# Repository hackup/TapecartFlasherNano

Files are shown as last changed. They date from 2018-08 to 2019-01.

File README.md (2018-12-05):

# TapecartFlasher Nano

This is a shield for Arduino Nano and compatible boards to be used with the software from the [TapecartFlasher project](https://github.com/detlefgerhardt/TapecartFlasher). It allows fast and easy transfer of data from a PC or a connected micro SD card to a [Tapecart](https://github.com/ikorb/tapecart) device. More details are available on [hackup.net](https://www.hackup.net/tag/tapecartflasher/).

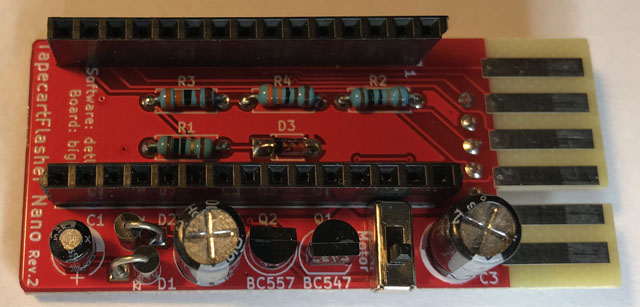
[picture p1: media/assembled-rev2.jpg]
TapecartFlasher Nano, Rev.2

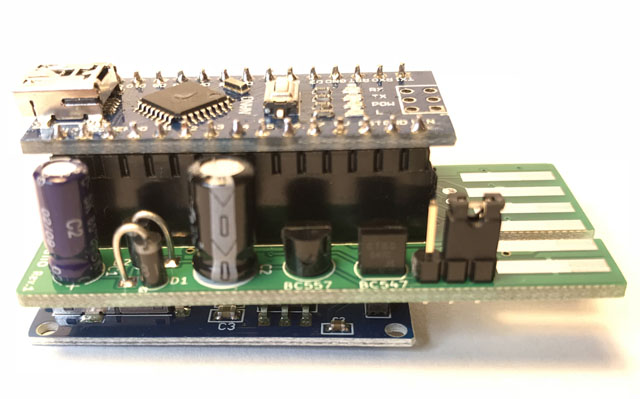
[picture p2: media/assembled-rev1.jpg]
TapecartFlasher Nano, Rev.1


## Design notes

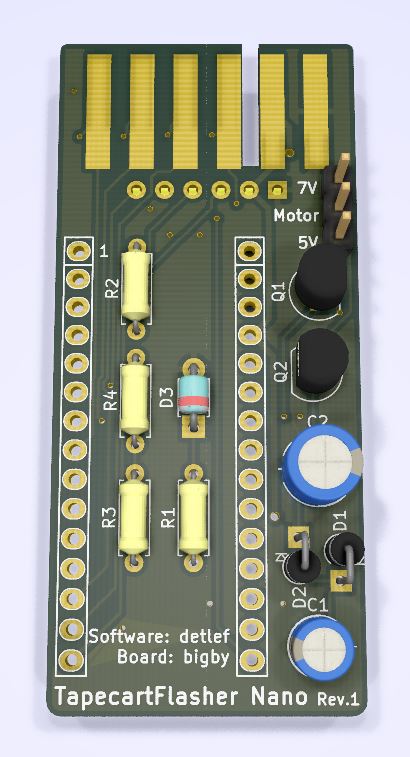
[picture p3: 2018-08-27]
media/TapecartFlasher-rev1-top.JPG

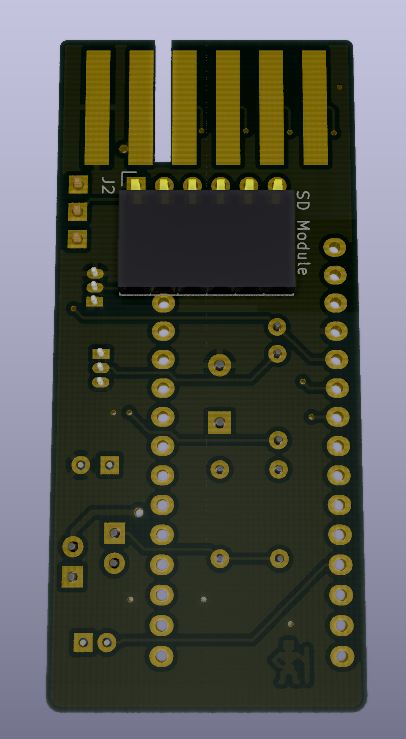
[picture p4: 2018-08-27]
media/TapecartFlasher-rev1-bottom.JPG

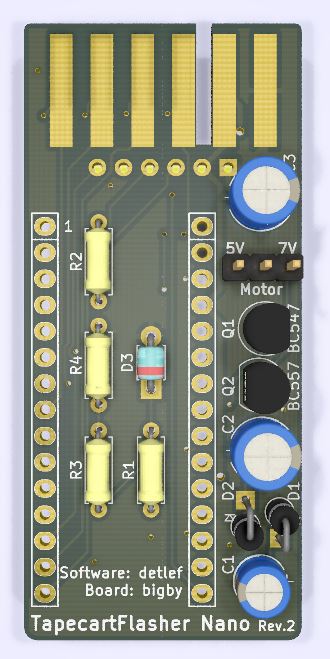
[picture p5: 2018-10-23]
media/TapecartFlasher-rev2-top.JPG

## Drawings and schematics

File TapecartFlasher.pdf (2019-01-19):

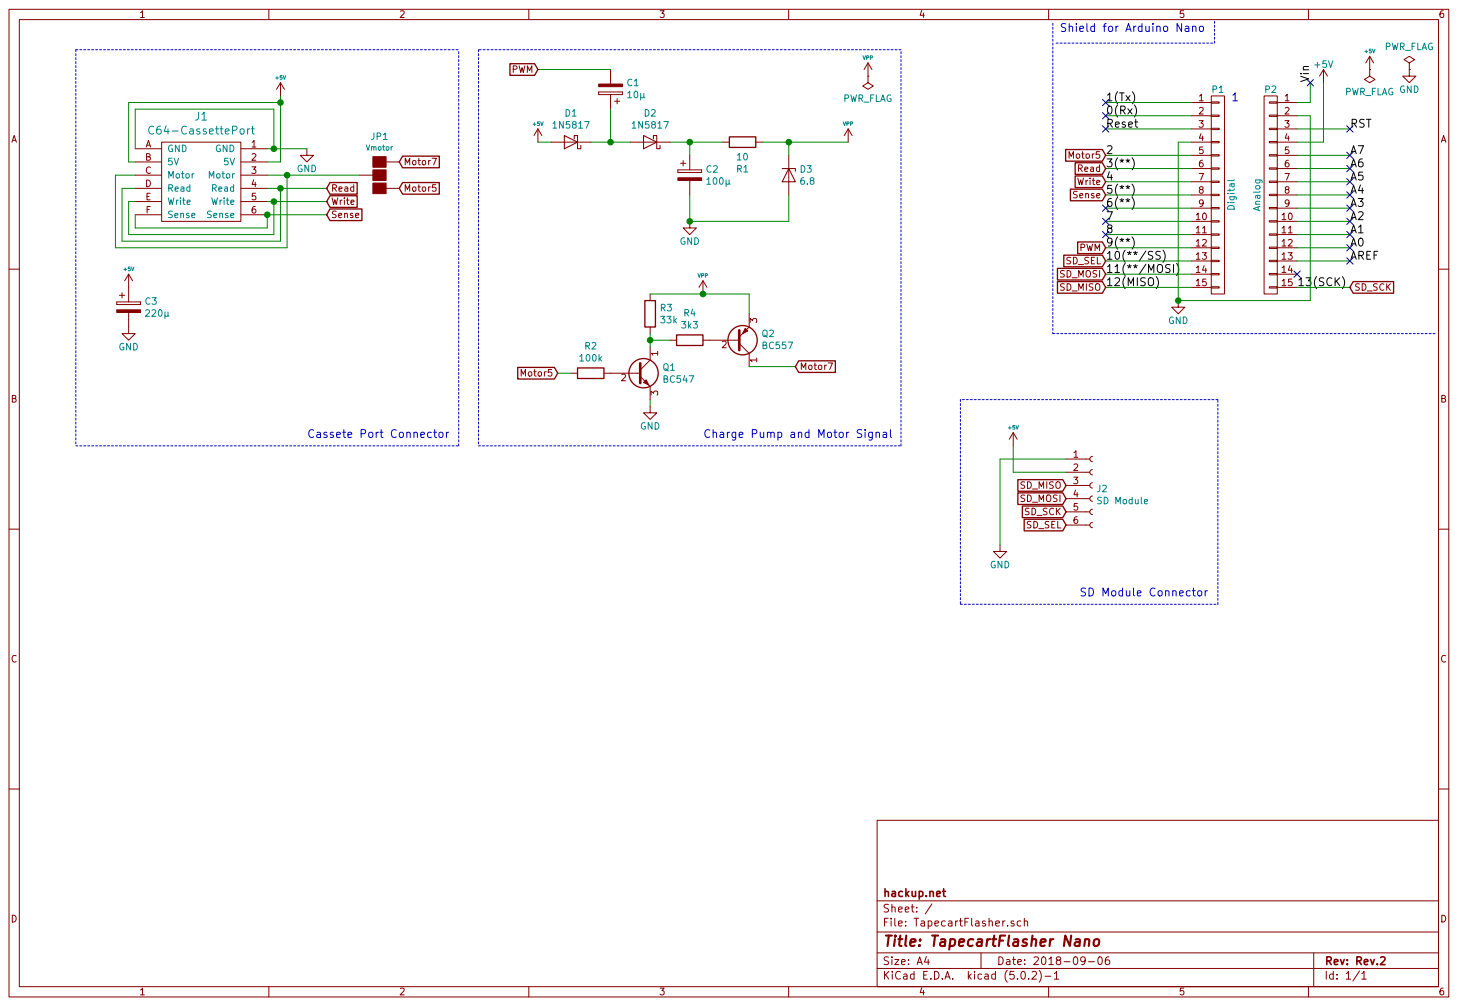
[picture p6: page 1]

File: TapecartFlasher.sch Sheet: / hackup.net

Id: 1/1 Title: TapecartFlasher Nano

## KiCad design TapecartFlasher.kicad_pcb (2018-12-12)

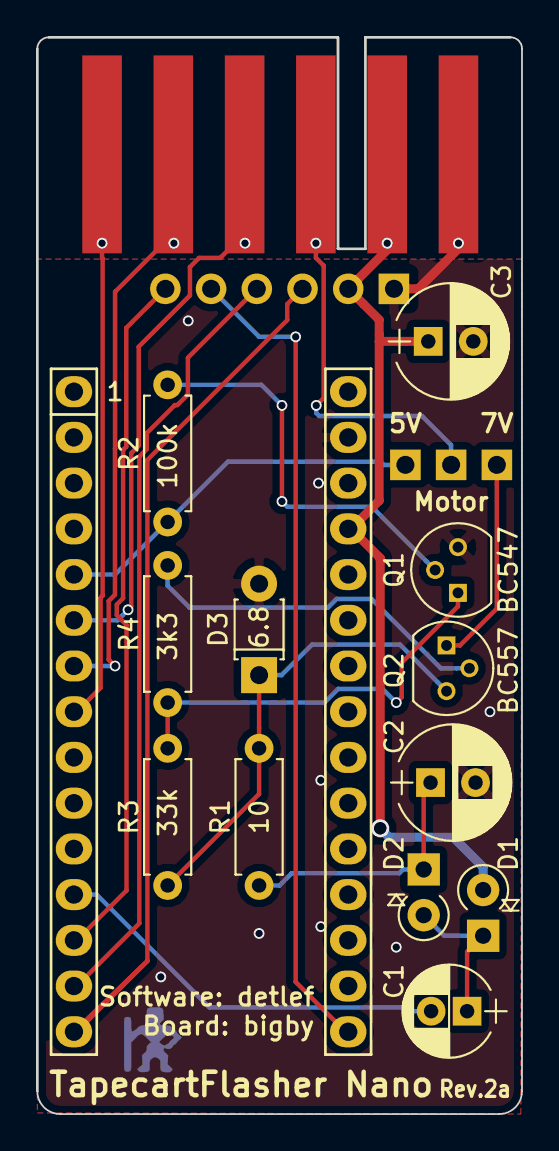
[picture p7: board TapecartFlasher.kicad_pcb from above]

Board: 2 copper layers, 26.9 x 59.8 mm, 17 parts (1 on the bottom side), 19 nets.

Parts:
C1: 10µ; CP_Radial_D5.0mm_P2.00mm
C2: 100µ; CP_Radial_D6.3mm_P2.50mm
C3: 220µ; CP_Radial_D6.3mm_P2.50mm
D1, D2: 1N5817; D_A-405_P2.54mm_Vertical_KathodeUp
D3: 6.8; D_T-1_P5.08mm_Horizontal
J1: C64-CassettePort; C64-Cassette-Port-Male
J2: SD Module; Socket_Strip_Angled_1x06_Pitch2.54mm
JP1: Vmotor; Pin_Header_Straight_1x03_Pitch2.54mm
P1: Digital; Socket_Strip_Arduino_1x15
P2: Analog; Socket_Strip_Arduino_1x15
Q1: BC547; TO-92_Molded_Narrow
Q2: BC557; TO-92_Molded_Narrow
R1: 10; R_Axial_DIN0207_L6.3mm_D2.5mm_P7.62mm_Horizontal
R2: 100k; R_Axial_DIN0207_L6.3mm_D2.5mm_P7.62mm_Horizontal
R3: 33k; R_Axial_DIN0207_L6.3mm_D2.5mm_P7.62mm_Horizontal
R4: 3k3; R_Axial_DIN0207_L6.3mm_D2.5mm_P7.62mm_Horizontal

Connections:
+5V: C3.1, D1.2, J1.2, J1.B, J2.2, P2.4
GND: C2.2, C3.2, D3.2, J1.1, J1.A, J2.1, P1.4, P2.2, Q1.3
Motor5: JP1.1, P1.5, R2.2
Motor7: JP1.3, Q2.1
unnamed: C1.1, D1.1, D2.2
unnamed: C2.1, D2.1, R1.1
unnamed: J1.3, J1.C, JP1.2
unnamed: Q1.1, R3.2, R4.2
unnamed: Q1.2, R2.1
unnamed: Q2.2, R4.1
PWM: C1.2, P1.12
Read: J1.4, J1.D, P1.6
SD_MISO: J2.3, P1.15
SD_MOSI: J2.4, P1.14
SD_SCK: J2.5, P2.15
SD_SEL: J2.6, P1.13
Sense: J1.6, J1.F, P1.8
VPP: D3.1, Q2.3, R1.2, R3.1
Write: J1.5, J1.E, P1.7

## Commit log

2018-08-26 Initial commit.
    [TapecartFlasher.kicad_pcb, TapecartFlasher.sch]
2018-08-26 Added SD module connector and motor voltage jumper.
    [TapecartFlasher.kicad_pcb, TapecartFlasher.sch]
2018-08-26 Renamed board.
    [TapecartFlasher.kicad_pcb, TapecartFlasher.sch]
2018-08-27 Preparing for Gerber export.
    [TapecartFlasher.kicad_pcb, TapecartFlasher.sch]
2018-08-27 Finialized revision 1.
    [TapecartFlasher.kicad_pcb]
2018-08-27 Project address should have been on there.
    [TapecartFlasher.kicad_pcb]
2018-09-04 Annotated schematics.
    [TapecartFlasher.sch]
2018-09-04 Changed resistor footprints.
    [TapecartFlasher.kicad_pcb, TapecartFlasher.sch]
2018-09-06 Modified/corrected zender diode circuit.
    [TapecartFlasher.kicad_pcb, TapecartFlasher.sch]
2018-10-23 Added decoupling capacitor to prevent Arduino from rebooting.
    [TapecartFlasher.kicad_pcb, TapecartFlasher.sch]
2018-10-24 Fixed gold fingers.
    [TapecartFlasher.kicad_pcb]
2018-12-04 Moved switch labels.
    [TapecartFlasher.kicad_pcb]
2018-12-12 Use local 3D model for socket strips that allow export to STEP.
    [TapecartFlasher.kicad_pcb]
2019-01-19 Added PDF export of the schematics.
